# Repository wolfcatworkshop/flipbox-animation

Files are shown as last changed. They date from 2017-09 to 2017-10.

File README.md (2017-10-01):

# flipbox-animation

Althought this is not a full how-to, you can find design files here in case you want to replicate this project. 
Read the full story [here](https://wolfcatworkshop.com/index.php/portfolio/drill-powered-flipbook-animation/) or go directly to a [video](https://vimeo.com/235196914) of the project in action.  

<p align="center"> 
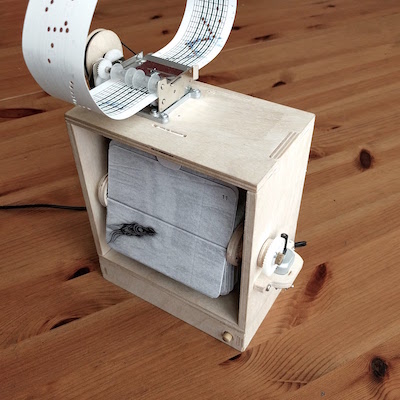
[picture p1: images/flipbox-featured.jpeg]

</p>

## Box Construction
<p align="center"> 
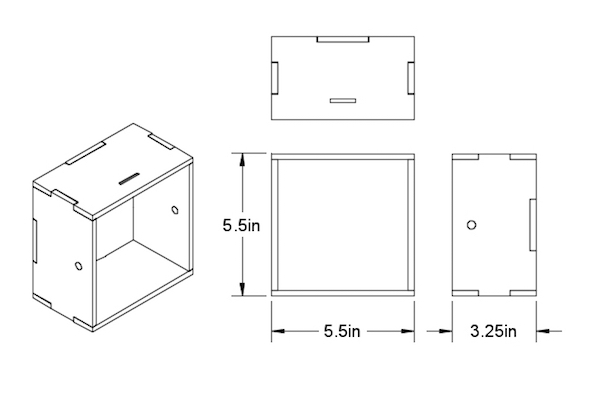
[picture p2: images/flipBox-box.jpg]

</p>

* All faces in a single file in the following formats: [DXF](/vector-files/all-box-faces.dxf), [AI](/vector-files/all-box-faces.ai), [SVG](/vector-files/all-box-faces.svg)
* Additional 1" bottom box for electronics in the following formats: [DXF](/vector-files/bottom-box.dxf), [AI](/vector-files/bottom-box.ai), [SVG](/vector-files/bottom-box.svg)

## Additional parts
* Frame holding wheel: [DXF](/vector-files/wheel.dxf), [AI](/vector-files/wheel.ai), [SVG](/vector-files/wheel.svg) and [STL](/stl-files/wheel.stl)(since this part is suitable for 3D printing).
* Small DC motor mount: [DXF](/vector-files/motor-mount.dxf), [AI](/vector-files/motor-mount.ai), [SVG](/vector-files/motor-mount.svg) and [STL](/stl-files/motor-mount.stl)

## Electronics
This project can be replicated with any number of Arduino compatible boards, in my case, for space saving purpuses I used an Attiny85.

* The speed of each motor is controlled via Pulse Width Modulation, because the microcontroller has a current and voltage limit, the switching is done by a transistor (see the [Transistor Motor Control](https://www.arduino.cc/en/Tutorial/TransistorMotorControl) example on the Arduino website).
* A small potentiometer serves as a physical interface to adjust the speed of each motor (see the [Reading a potentiometer](https://www.arduino.cc/en/tutorial/potentiometer) example).
* There is a single button to start the operation and start the timer, so every time you press the button the animation plays for 1 minute and then stops (see [Button Tutorial](https://www.arduino.cc/en/Tutorial/Button) and [Debounce Tutorial](https://www.arduino.cc/en/Tutorial/Debounce)).

**The specifics of my final circuit are as follows:**
* Attiny85 chip running with internal 1 MHZ clock
* Powered by a 12v, 300 mA wall wart
* Power is regulated by an L7805 voltage regulator with two electrolytic capacitors
   * 10 uF on the input
   * 47 uF on the output
* Each motor control switches 12 v using:
   * TIP112 transistor
   * 1N4001 Diode
   * 270 Ohm resistor
* Trimpots are 10 K ohm outside legs connected to 5v and Ground, middle leg to pins A1 and A2 respectively
* Switch uses a pull-down 10 k resistor connected to ground and the other leg to 5v
* Arduino [Code](/code/arduino-Sketch.ino)

Note that in the above code the analog pins are referenced as A1, A2, and A3 which works with the Attiny85 microcontroller but not with other boards. Also, I changed the PWM frequency on line 75 to get rid of the motor buzzing at low speeds but this affects the delay() and millis() functions. Read more about compesanting for this at https://playground.arduino.cc/Main/TimerPWMCheatsheet

More of my work at https://wolfcatworkshop.com

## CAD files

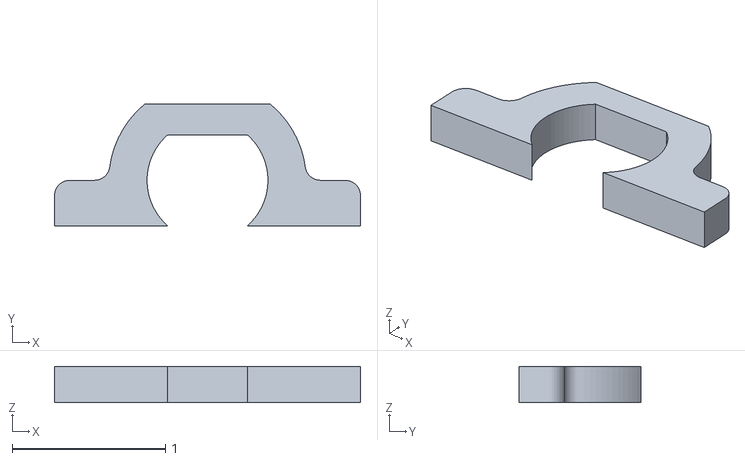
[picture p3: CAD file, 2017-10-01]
stl-files/motor-mount.stl
2.00 x 0.795 x 0.236

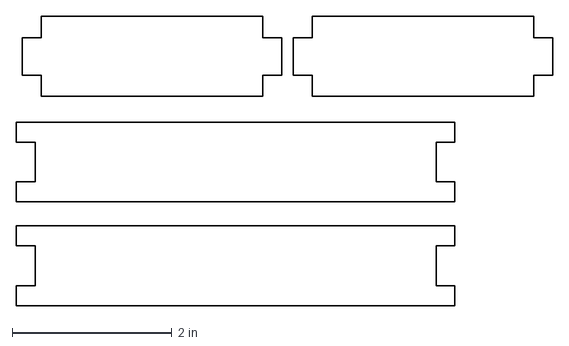
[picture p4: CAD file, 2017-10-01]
vector-files/bottom-box.dxf
6.73 x 3.63 in

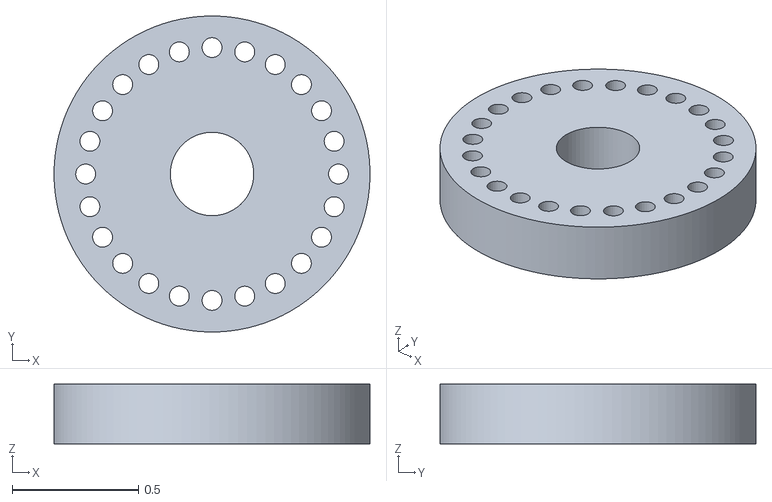
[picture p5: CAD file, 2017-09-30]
stl-files/wheel.stl
1.25 x 1.25 x 0.236

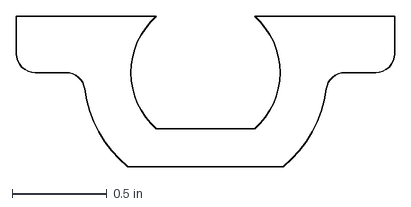
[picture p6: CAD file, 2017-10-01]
vector-files/motor-mount.dxf
2.00 x 0.795 in

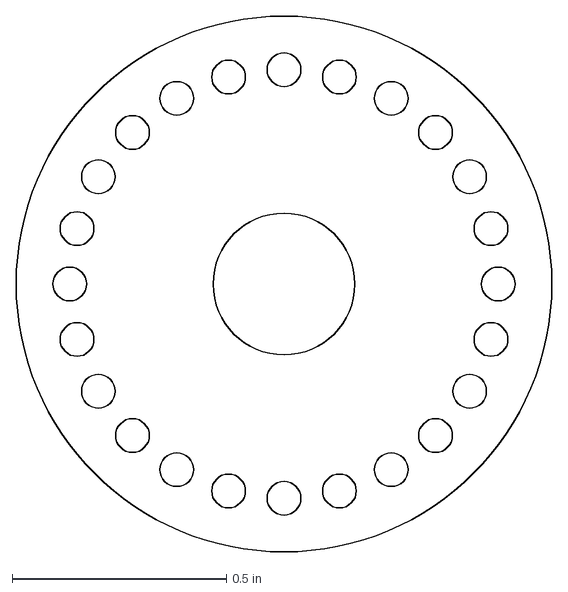
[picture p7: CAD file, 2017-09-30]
vector-files/wheel.dxf
1.25 x 1.25 in

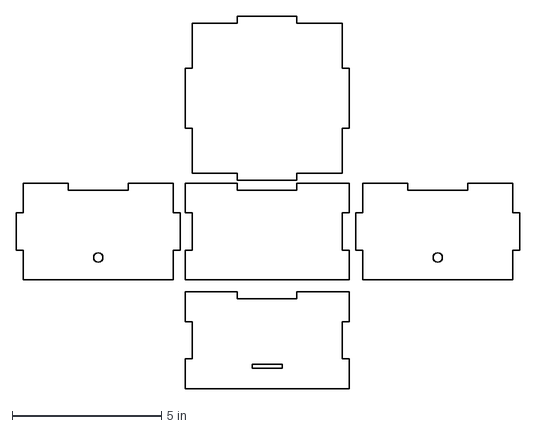
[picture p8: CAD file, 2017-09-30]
vector-files/all-box-faces.dxf
16.9 x 12.5 in

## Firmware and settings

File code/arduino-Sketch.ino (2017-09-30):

/*
This sketch uses an attiny85 to control two small DC motors via
PWM. To make manual speed calibration easier I added two 10 K ohm trimpots
that are read by analog pins A1 and A2. 

One button connected to pin A3 starts a timer so the motors run
for a defined number of milliseconds.

The circuit:
  - Attiny85 chip running with internal 1 MHZ clock
  - Powered by a 12v 300 mA wall wart
  - Regulated by an L7805 voltage regulator with electrolitic capacitors
    - 10 uF on the input
    - 47 uF on the output
  - Each motor control switches 12 v using
    - TIP112 transistor
    - 1N4001 Diode
    - 270 Ohm resistor
  - Trim pots are 10 K ohm outside legs connected to 5v and Ground, 
    middle leg to pins A1 and A2 respectively
  - Switch uses a pull down 10 k resistor connected to ground and
    the other leg to 5v

Resources:
  - Motor circuit and code (TIP112 instead of N2222:  https://learn.adafruit.com/adafruit-arduino-lesson-13-dc-motors/
  - Motor transistor circuit: https://www.arduino.cc/en/Tutorial/TransistorMotorControl
  - Button circuit and code: https://www.arduino.cc/en/Tutorial/Button
  - Reading a Potentiometer: https://www.arduino.cc/en/tutorial/potentiometer
  - Timer function takes hints from the debounce example: https://www.arduino.cc/en/Tutorial/Debounce
  - Use hints for attiny85: https://learn.sparkfun.com/tutorials/tiny-avr-programmer-hookup-guide/attiny85-use-hints


Federico
https://wolfcatworkshop.com
more about this project at https://wolfcatworkshop.com/index.php/portfolio/drill-powered-flipbook-animation/
  
 */


//variables
int motorPin0    = 0;  //Motor 
int motorPin1    = 1;  //Motor 
int analogInPin1 = A1; //Analog Pin 1 for 10 k pot
int analogInPin2 = A2; //Analog Pin 2 for 10 k pot
int buttonPin    = A3; //Button 

int analogIn1;  //stores readings from A1
int analogIn2;  //stores readings from A2

int buttonState;    //reading for the button, either HIGH or LOW
int motorState;     //Motors ON or OFF (0 or 1)


long seconds = 8000;  //See note below about changing the PWM frequency and its effect on delay and millis
//Using unsigned longs for milliseconds because the number gets larger than
//what can be stored in an int
unsigned long lastTime = seconds * 60;       // the last time the button pin was toggled
unsigned long timerDelay = seconds * 60;    // how long until next read



void setup() {

//set up all the pins  
    pinMode(motorPin0,    OUTPUT);
    pinMode(motorPin1,    OUTPUT);
    pinMode(analogInPin1, INPUT);
    pinMode(analogInPin2, INPUT);
    pinMode(buttonPin,    INPUT);

/* Change the PWM frequency to avoid buzzing, more at http://forum.arduino.cc/index.php?topic=174349.0
This setting affects delay and millis() https://playground.arduino.cc/Main/TimerPWMCheatsheet 
On the attiny85 this line affects both PMW pins
One second: 8000 millis with 0x02 (which is divisor 8 of the frequency)
*/
    TCCR0B = TCCR0B & 0b11111000 | 0x02; //see comment above
}


void loop() {
  
int analogIn1 = analogRead(analogInPin1); // Read analog voltage on pin A1
int analogIn2 = analogRead(analogInPin2); // Read analog voltage on pin A2  

/*  This turns the motors ON or OFF depending on the value of motorState
    analogRead returns a value between 0 and 1023, dividing this by four turns
    it into a value between 0 and 255 which is the range analogWrite can use
*/
  if (motorState == 1){
    analogWrite(motorPin0, analogIn1/4); 
    analogWrite(motorPin1, analogIn2/4);
  }
  else {
    analogWrite(motorPin0, 0);
    analogWrite(motorPin1, 0);
    };


/*
The timer takes hints from the Debaounce example on the arduino website
Only cares about the state of the button pin if the current time - the last time is
bigger than the specified delay. 

*/
buttonState = digitalRead(buttonPin);  // larger than delay they read the button  

if (millis() - lastTime > timerDelay){   //if current time minus last time is 
    
     if (buttonState == HIGH){     //if the button is pressed
      lastTime = millis();          //reset the time
      motorState = 1;              //and turn on the motors
      }
     else{
      motorState = 0;              //motors OFF if nothing happens
      }

        };
  

  
    
}
  
  


  
